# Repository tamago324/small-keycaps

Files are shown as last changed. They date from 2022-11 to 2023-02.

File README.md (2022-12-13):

* 底面が16mm
* 高さが6mm、高さが7mm (くらい)

参考情報
* [キースイッチのデータシート](https://datasheet.octopart.com/MX1A-11NW-Cherry-datasheet-34676.pdf)
* [キーキャップ設計による OpenSCAD 入門 \- Qiita](https://qiita.com/zk_phi/items/ab99315ebaef66e84aa0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)

## ライセンス

<br />この 作品 は <a rel="license" href="http://creativecommons.org/licenses/by-nc/4.0/">クリエイティブ・コモンズ 表示 - 非営利 4.0 国際 ライセンス</a>の下に提供されています。

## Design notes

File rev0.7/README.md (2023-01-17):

## これはなに？

底面が16mmの Cherry プロファイル風なキーキャップです。

また、JLCPCB の MJF で発注するようにステムを調整しています。
ニッパーでパチパチ切れます

## 実行方法

src/keycaps で出力したい形の module を呼び出すように編集
また、`keycap_u_size` でサイズを変更可能 (1 と 1.25 は確認済み)

例) R2 を `src/keycaps_r2.stl` として出力する

```
openscad -o "stl/keycaps_r2.stl" "src/keycaps.scad"
```

## 発注

JLCPCB に発注することを想定しています。
発注するときのオプションは以下のようにします。

* 3D Technology: MJF(Nylon)
* Material: PA12-HP Nylon
* Color: Dyed Black

また、`0.8mm wall thickness detected` のような渓谷が表示されますが、`Yes` を選んで発注をします。

## 参考

* https://github.com/bbrfkr/lhs-profile-keycap
  * こちらの convex と home の作り方を参考にしました。

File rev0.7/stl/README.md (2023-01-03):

## stl ファイル

* keycaps_all.stl: R2〜R4 までのキーが2個ずつ、ホームのキーが2つ、1uコンベックスが2つ
* keycaps_convex.stl: 1uコンベックスが6個、1.25uコンベックスが4個
* keycaps_r2.stl: R2 を10個
* keycaps_r3.stl: R3 を10個
* keycaps_r4.stl: R4 を10個

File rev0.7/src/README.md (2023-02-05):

* keycaps.scad
  * R2、R3、R4、コンベックス のキーキャップ

## 0.6 からの変更点

* ホームポジションのぽっちを大きくした

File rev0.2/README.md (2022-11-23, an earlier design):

## 実行方法

```
openscad -o "stl/keycaps_r2.stl" "src/keycaps.scad"
```

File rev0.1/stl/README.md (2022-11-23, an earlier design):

## STLファイル

* 高さが6mm
 keycaps_r2_h6.stl (親指キーにも使えそう)
 keycaps_standard_h6.stl

* 高さが7mm
 keycaps_r2_h7.stl
 keycaps_r3_h7.stl
 keycaps_r4_h7.stl
 keycaps_standard_h7.stl

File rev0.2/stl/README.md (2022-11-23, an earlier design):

## STLファイル

### 上に1だけずらしたもの

keycaps_r2_shift.stl
keycaps_r3_shift.stl
keycaps_r4_shift.stl

### ずらしていないもの

keycaps_r2.stl
keycaps_r3.stl
keycaps_r4.stl

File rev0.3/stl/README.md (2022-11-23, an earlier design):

## STLファイル

keycaps_r2_shift.stl
keycaps_r3_shift.stl
keycaps_r4_shift.stl

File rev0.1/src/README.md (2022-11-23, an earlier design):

* keycaps.scad
  * R2、R3、R4 のキーキャップ
* keycap_standard.scad
  * 上が平面のキーキャップ

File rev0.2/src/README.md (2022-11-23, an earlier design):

* keycaps.scad
  * R2、R3、R4 のキーキャップ
* keycap_standard.scad
  * 上が平面のキーキャップ
* convex.scad
  * コンベックスキー
  * TODO: 未完成だから、作りたい

## 変更点

* R3とR4の高さを変更
* ステムを少しだけ広げた

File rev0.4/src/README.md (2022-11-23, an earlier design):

* keycaps.scad
  * R2、R3、R4、コンベックス のキーキャップ

## 変更点

* ステムを少し小さくした
  * rev0.4 だとちょっと緩かったため、小さくした
* コンベックスキーを追加
* ホームキーの作成

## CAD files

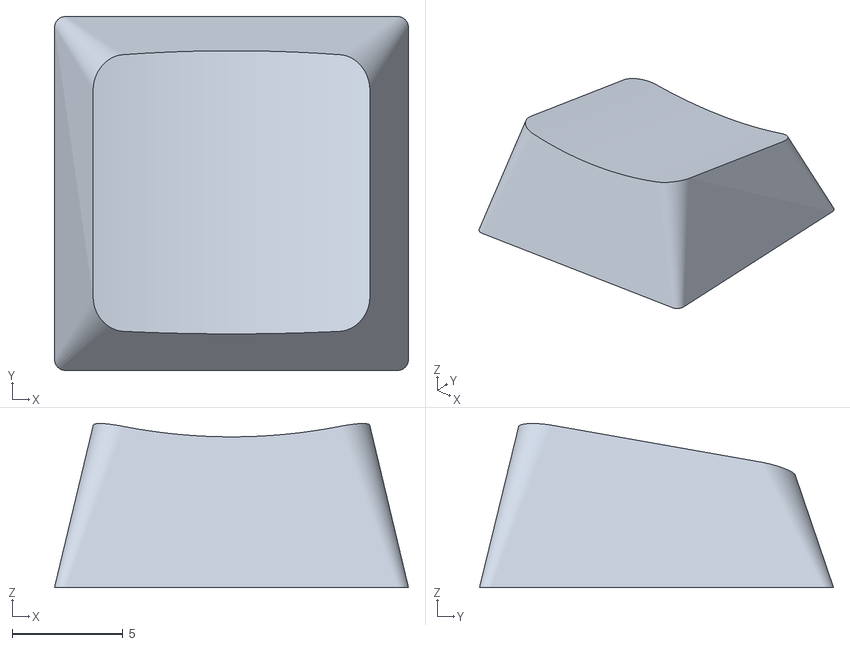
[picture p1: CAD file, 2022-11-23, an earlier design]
rev0.1/stl/keycaps_r4_h7.stl
16.0 x 16.0 x 7.41

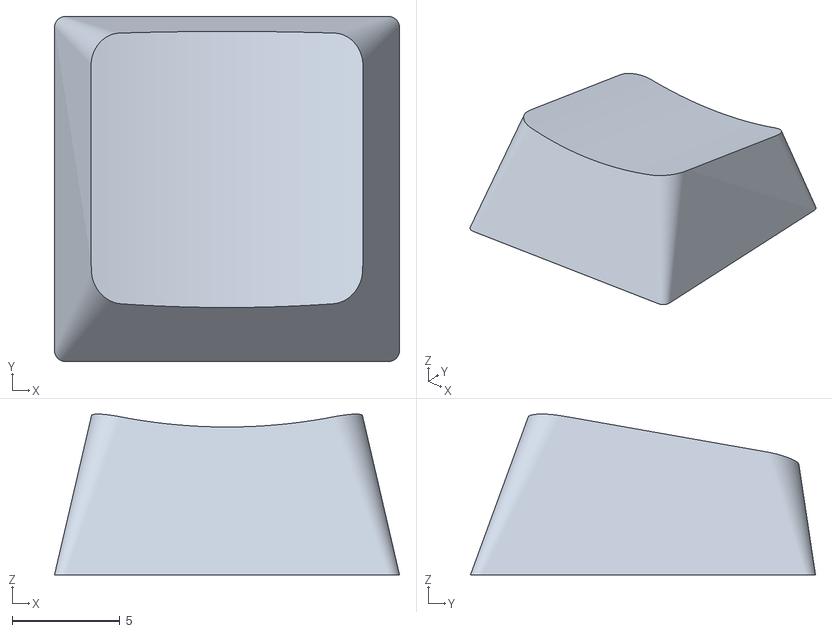
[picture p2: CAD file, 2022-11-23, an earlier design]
rev0.2/stl/keycaps_r4.stl
16.0 x 16.0 x 7.46

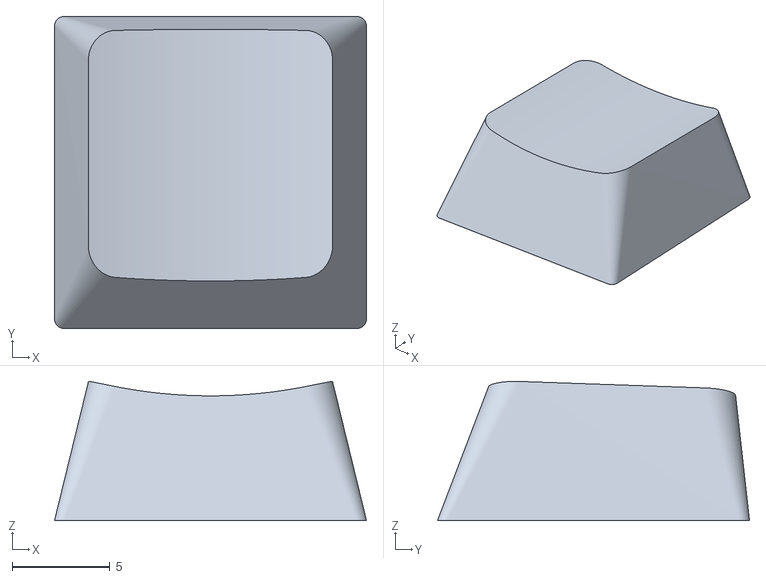
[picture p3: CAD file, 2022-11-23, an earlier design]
rev0.3/stl/keycaps_r2.stl
16.0 x 16.0 x 7.14

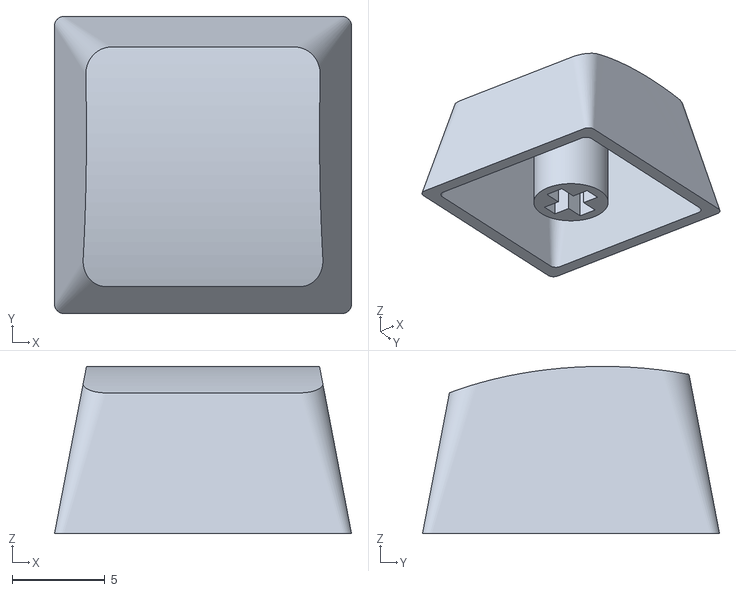
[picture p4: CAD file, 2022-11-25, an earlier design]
rev0.4/stl/keycaps_convex.stl
16.0 x 16.0 x 9.00

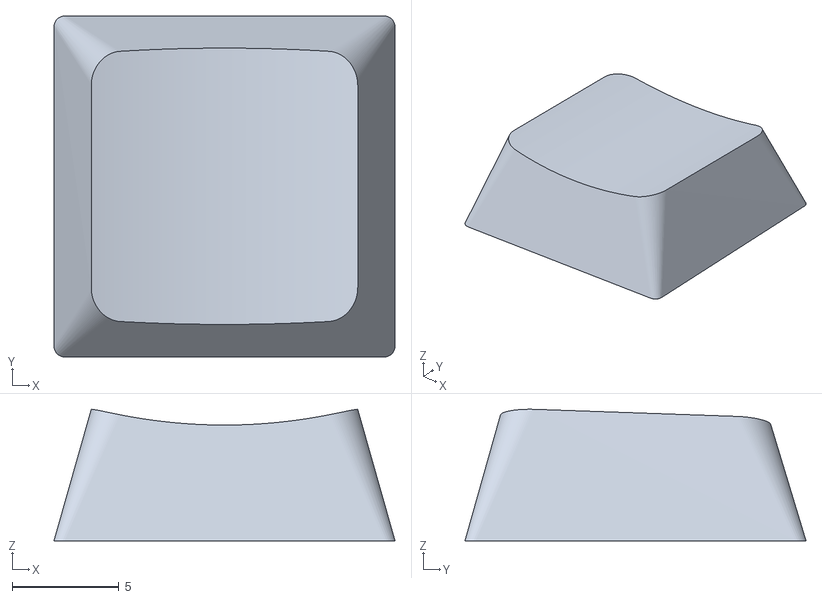
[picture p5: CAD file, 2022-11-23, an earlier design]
rev0.1/stl/keycaps_r2_h6.stl
16.0 x 16.0 x 6.17

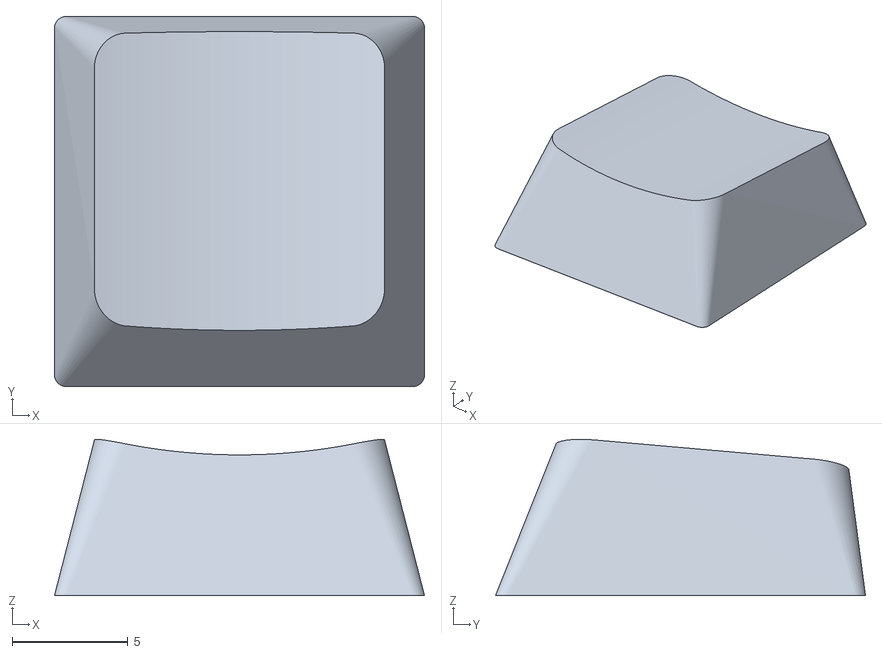
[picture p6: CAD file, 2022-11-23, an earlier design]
rev0.2/stl/keycaps_r3.stl
16.0 x 16.0 x 6.76

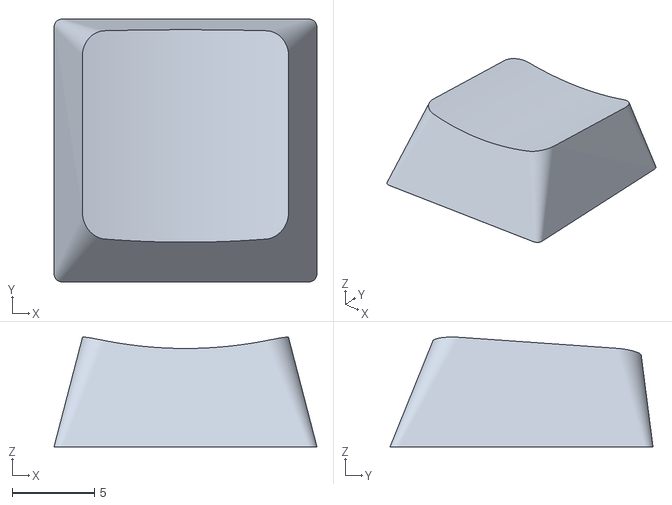
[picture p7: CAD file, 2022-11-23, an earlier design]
rev0.3/stl/keycaps_r3.stl
16.0 x 16.0 x 6.69

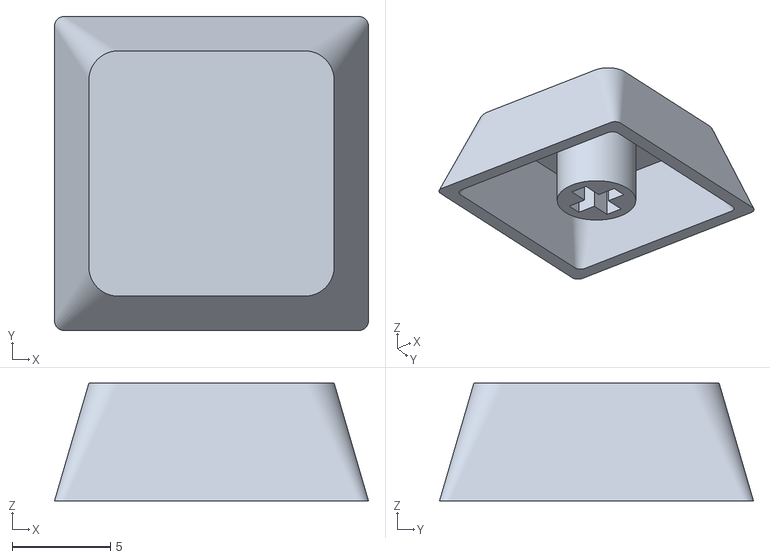
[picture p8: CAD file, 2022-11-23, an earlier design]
rev0.1/stl/keycaps_standard_h6.stl
16.0 x 16.0 x 6.01

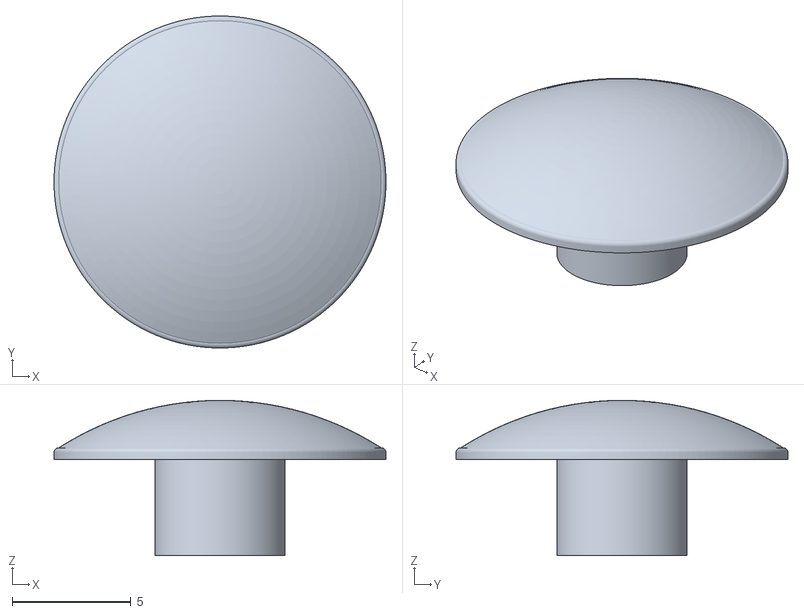
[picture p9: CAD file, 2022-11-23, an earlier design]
rev0.3/stl/convex 16mm 2.0.stl
14.0 x 14.0 x 6.55

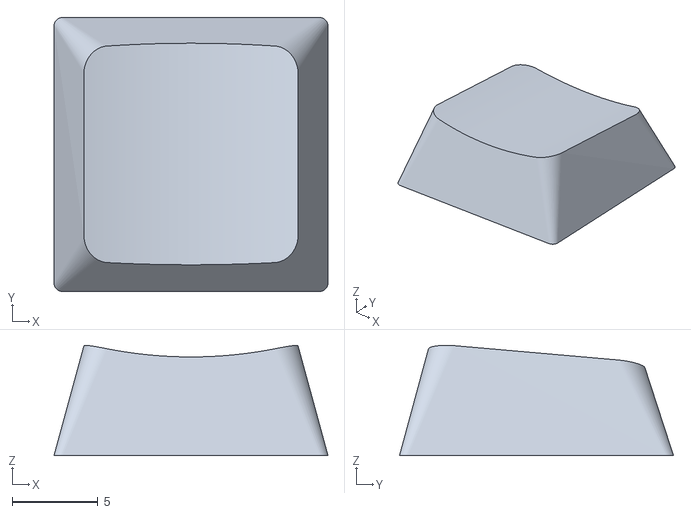
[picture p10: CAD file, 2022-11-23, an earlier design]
rev0.1/stl/keycaps_r3_h7.stl
16.0 x 16.0 x 6.44

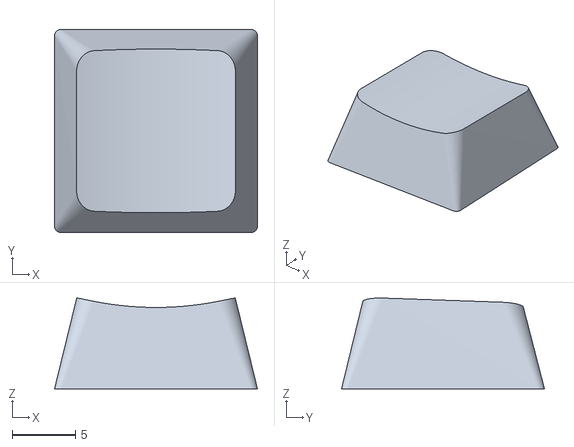
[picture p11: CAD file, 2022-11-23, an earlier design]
rev0.2/stl/keycaps_r2_shift.stl
16.0 x 16.0 x 7.17

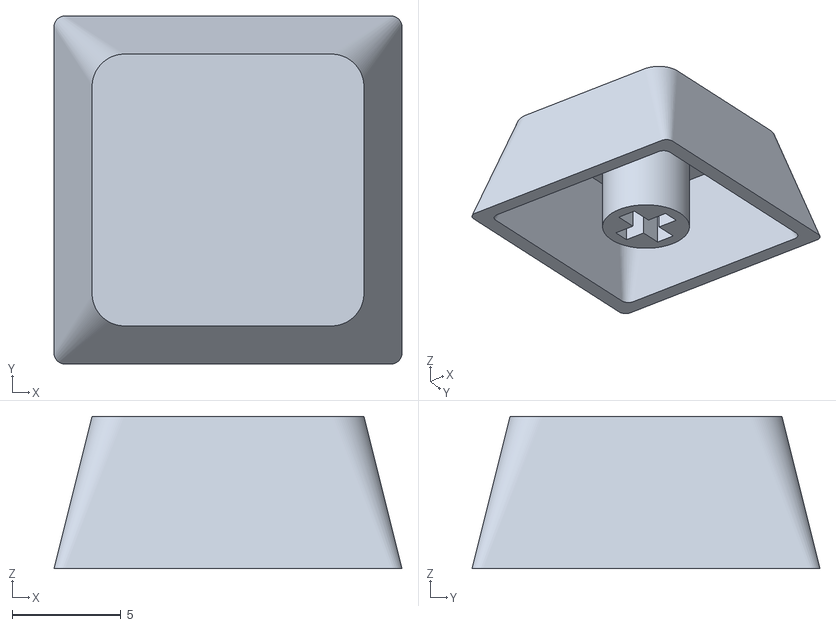
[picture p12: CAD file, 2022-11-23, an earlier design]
rev0.1/stl/keycaps_standard_h7.stl
16.0 x 16.0 x 7.01

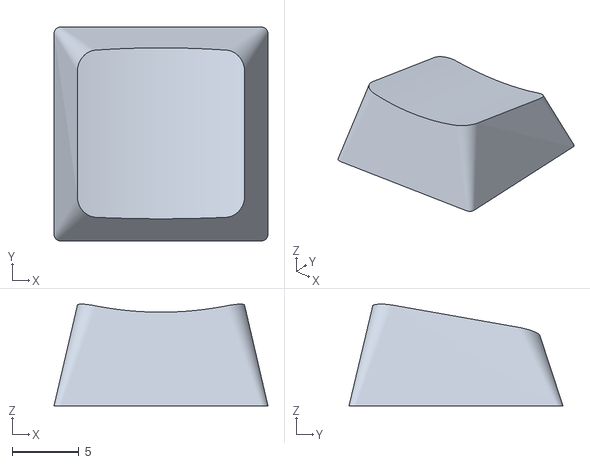
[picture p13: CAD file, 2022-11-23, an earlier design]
rev0.2/stl/keycaps_r4_shift.stl
16.0 x 16.0 x 7.61

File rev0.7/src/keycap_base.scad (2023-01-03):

$fs = 0.1;
$fa = 0.25;  // くり抜く円柱を作成のため、精度を上げる

use <stem.scad>

key_bottom = 16;
key_top = 12.5;

// 基準の高さ
base_height = 7;

// --------
// キャップ部分
// --------

// 角が丸い四角
module rounded_cube(size, r) {
  // cylinder の高さ (適当な値)
  h = 0.0001;
  minkowski() {
    cube([size[0] - r*2, size[1] - r*2, size[2] - h], center = true);
    cylinder(r = r, h = h);
  }
}

// くり抜くための円を作成する
function dish_r(w, d) = (w * w + 4 * d) / (8 * d);

// 四角
module keycap_outer_shape(key_bottom_size, key_top_size, key_top_height, angle, u_size, dish_depth, shift_upword) {
  difference() {
    // 基本的なキーキャップを作成
    base_cube(key_bottom_size, key_top_size, key_top_height, u_size, angle, shift_upword);

    // くり抜く円柱を作成
    translate([0, 0, key_top_height])
      rotate([- angle, 0, 0])
      translate([0, 0, dish_r(key_top_size*u_size, dish_depth) - dish_depth])
        rotate([90, 0, 0])
        cylinder(r = dish_r(key_top_size*u_size, dish_depth), h = 60, center = true);
  }
}

// 基本的なキーキャップを作成
module base_cube(key_bottom_size, key_top_size, key_top_height, u_size, angle, shift_upword) {
  hull() {
    // cherry プロファイルっぽく上にずらす
    translate([0, shift_upword, key_top_height])
      rotate([- angle,  0, 0])
        rounded_cube([key_top_size*u_size, key_top_size, 0.01], 1.5);
    rounded_cube([key_bottom_size*u_size, key_bottom_size, 0.01], 0.5);
  }
}

// キーキャップのくり抜くための四角
module keycap_inner_shape(bottom, top, height, angle, u_size, depth, shift_upword) {
    thickness = 1;
    keycap_outer_shape(bottom - (thickness * 2), top - (thickness * 2), height - thickness, angle, u_size, depth, shift_upword);
}

// スイッチ部分をくり抜いてキーキャップを作成
module keycap_shape(bottom, top, height, u_size, angle, shift_upword) {
  depth = 0.8;
  difference () {
    keycap_outer_shape(bottom, top, height, angle, u_size, depth, shift_upword);
    keycap_inner_shape(bottom, top, height, angle, u_size, depth, shift_upword);
  }
}

module keycap(key_height, key_angle, u_size = 1.0, shift_upword = 0) {

  keycap_shape(key_bottom, key_top, key_height, u_size, key_angle, shift_upword);

  // キーキャップと合わせられるステムを作成
  intersection() {
    stem();
    // キートップの厚さは1.5mmとする
    keycap_outer_shape(key_bottom, key_top, key_height, key_angle, u_size, 1.5, shift_upword);
  }
}

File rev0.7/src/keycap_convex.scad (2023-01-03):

include <keycap_base.scad>
use <stem.scad>

// コンベックスキー
convex_key_height = base_height + 0.5;
convex_key_top = key_top * ((convex_key_height * (key_top / key_bottom)) / (base_height - 1));
/* convex_key_height = base_height + 2;                                                       */
/* convex_key_top = key_top * ((convex_key_height * (key_top / key_bottom)) / (base_height)); */

module convex_outershape(key_bottom_size, key_top_size, key_top_height, u_size) {
  intersection(){
    // コンベックスの円柱と重なるように、四角を長めに作成しておく
    base_cube(key_bottom_size, key_top_size, key_top_height, u_size, angle=0, shift_upword =0.8);
    rotate([0,90,0]) {
        $fn=128;
        // この丸みを小さくすると、丸くなる
        convex_value = 1.7;
        scale([1,convex_value,1])
          translate([0, 1, 0])
          cylinder(key_bottom_size*u_size,key_top_height,key_top_height,true);
    }
  }
}

module convex_innershape(bottom, top, height, u_size) {
  thickness = 1;
  convex_outershape(bottom - (thickness * 2), top - (thickness * 2), height - thickness, u_size);
  /* base_cube(bottom - (thickness * 2), top - (thickness * 2), height - thickness, angle=0, shift_upword=0); */
}

module convex_shape(bottom, top, height, u_size) {
  difference () {
    convex_outershape(bottom, top, height, u_size);
    convex_innershape(bottom, top, height, u_size);
  }
}

// コンベックスキー
module keycap_convex(u_size=1.0) {
  convex_shape(key_bottom, convex_key_top, convex_key_height, u_size);

  // キーキャップと合わせられるステムを作成
  intersection() {
    stem();
    // キートップの厚さは1.5mmとする
    convex_outershape(key_bottom, convex_key_top, convex_key_height, u_size);
  }
}

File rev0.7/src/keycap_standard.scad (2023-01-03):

include <keycap_base.scad>

// 四角
module keycap_outer_shape (key_bottom_size, key_top_size, key_top_height, angle, dish_depth) {
  top_r = 1.5;
  bottom_r = 0.5;

  // 基本的なキーキャップを作成
  hull() {
    translate([0, 0, key_top_height])
      rotate([- angle,  0, 0])
        rounded_cube([key_top_size, key_top_size, 0.01], top_r);
    rounded_cube([key_bottom_size, key_bottom_size, 0.01], bottom_r);
  }
}

// スイッチ部分をくり抜いてキーキャップを作成
module keycap_shape(bottom, top, height, angle) {
  depth = 0.8;
  difference () {
    keycap_outer_shape(bottom, top, height, angle, depth); 
    keycap_inner_shape(bottom, top, height, angle, depth);
  }
}

module keycap_standard(key_height, key_angle) {
  keycap_shape(key_bottom, key_top, key_height, key_angle);

  // キーキャップと合わせられるステムを作成
  intersection() {
    stem();
    // キートップの厚さは1.5mmとする
    keycap_outer_shape(key_bottom, key_top, key_height, key_angle, 1.5);
  }
}

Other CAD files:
rev0.4/stl/keycaps_r3.stl
rev0.2/stl/keycaps_r2.stl
rev0.4/stl/keycaps_r4.stl
rev0.3/stl/keycaps_r4.stl
rev0.4/stl/keycaps_r2.stl
rev0.7/src/keycaps.scad
rev0.1/src/convex.scad
rev0.1/src/keycap_base.scad
rev0.1/src/keycap_standard.scad
rev0.1/src/keycaps.scad
rev0.1/src/stem.scad
rev0.1/stl/keycaps_r2_h7.stl
rev0.2/src/convex.scad
rev0.2/src/keycap_base.scad
rev0.2/src/keycap_standard.scad
rev0.2/src/keycaps.scad
rev0.2/src/stem.scad
rev0.2/stl/keycaps_r3_shift.stl
rev0.3/src/convex.scad
rev0.3/src/keycap_base.scad
rev0.3/src/keycap_standard.scad
rev0.3/src/keycaps.scad
rev0.3/src/stem.scad
rev0.4/src/keycap_base.scad
rev0.4/src/keycap_convex.scad
rev0.4/src/keycap_standard.scad
rev0.4/src/keycaps.scad
rev0.4/src/stem.scad
rev0.4/stl/keycaps_home.stl
rev0.7/src/runner.scad
rev0.7/src/stem.scad

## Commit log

2022-12-13 ライセンス追加
2023-01-03 add rev0.6
    [keycap_base.scad, keycap_convex.scad, keycap_standard.scad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]
2023-02-05 rev0.7 追加
    [keycap_base.scad, keycap_convex.scad, keycap_standard.scad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]

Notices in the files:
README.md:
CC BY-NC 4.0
